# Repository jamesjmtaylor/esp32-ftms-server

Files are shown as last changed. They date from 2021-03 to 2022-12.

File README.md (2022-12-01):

# esp32-ftms-server

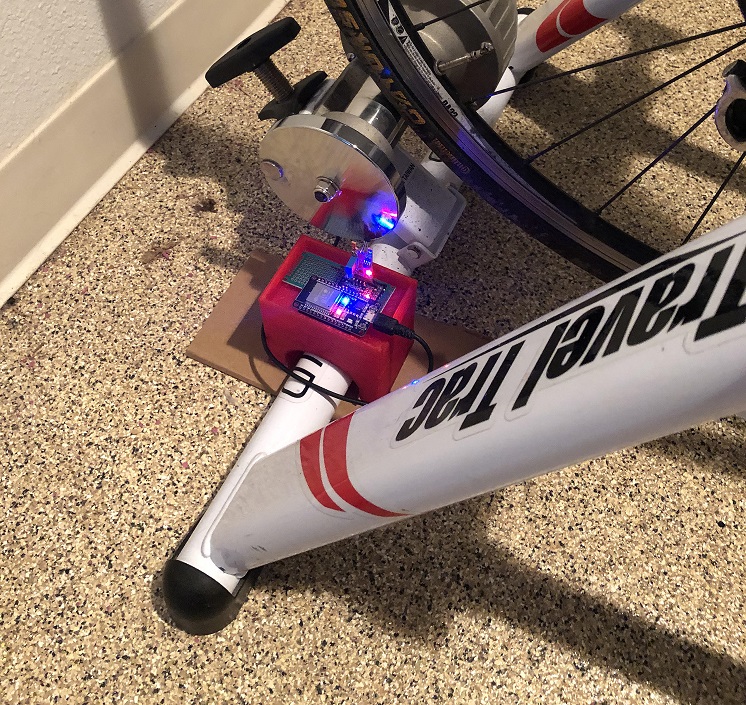
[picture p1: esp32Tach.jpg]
Tachometer
 

This is an ESP-32 based tachometer that I built for my stationary bike stand.  It uses the [Indoor Bike Data characteristic](https://www.bluetooth.com/wp-content/uploads/Sitecore-Media-Library/Gatt/Xml/Characteristics/org.bluetooth.characteristic.indoor_bike_data.xml) of the FTMS BLE service.

## Parts List

* [MELIFE 2 Pack for ESP32](https://www.amazon.com/MELIFE-Development-Dual-Mode-Microcontroller-Integrated/dp/B07Q576VWZ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)
* [ELEGOO 32 Pcs Double Sided PCB Board Prototype Kit](https://www.amazon.com/ELEGOO-Prototype-Soldering-Compatible-Arduino/dp/B072Z7Y19F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)
* [ELEGOO Upgraded 37 in 1 Sensor Modules Kit](https://www.amazon.com/ELEGOO-Upgraded-Tutorial-Compatible-MEGA2560/dp/B01MG49ZQ5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)
* [HATCHBOX ABS 3D Printer Filament](https://www.amazon.com/HATCHBOX-3D-Filament-Dimensional-Transparent/dp/B00M0CS6HA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)

## 3d Print Settings

The Cura 3d print settings for the tachMount.stl are below:

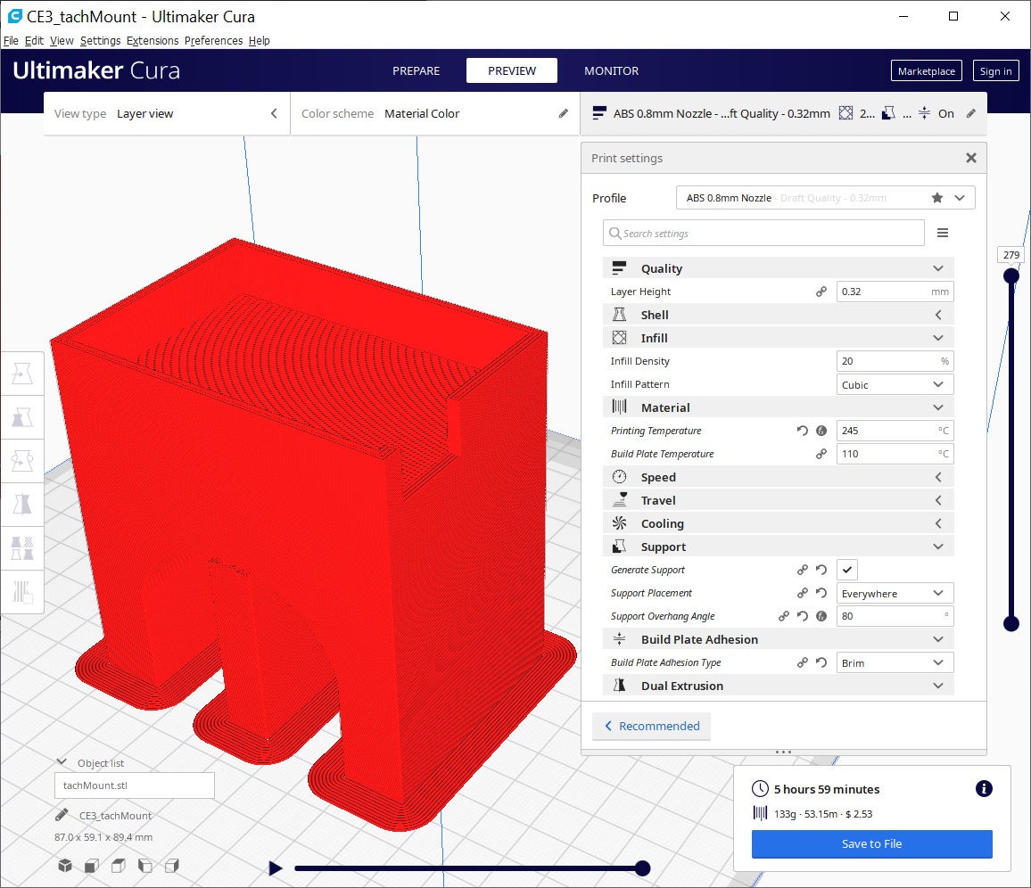
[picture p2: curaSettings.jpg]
Cura settings


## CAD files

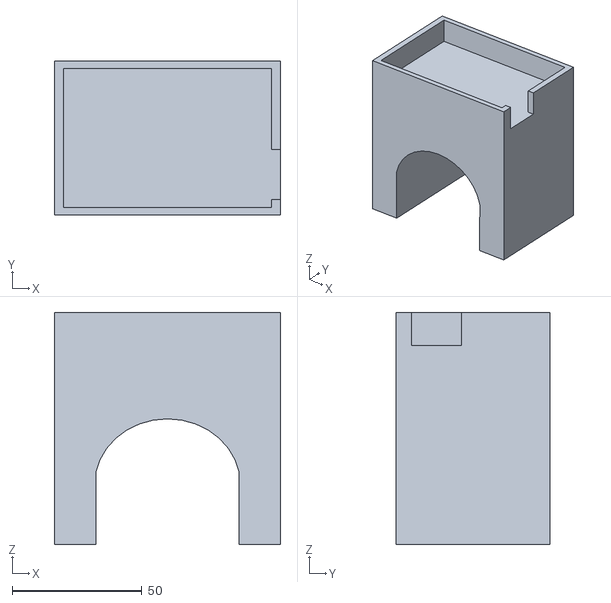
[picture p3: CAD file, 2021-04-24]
tachMount.stl
87.0 x 59.1 x 89.4

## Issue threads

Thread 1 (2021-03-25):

Cadence != RPM

jamesjmtaylor, 2021-03-25:
Cadence measures how fast the crankshaft rotates.  RPM measures how fast the road wheel rotates.

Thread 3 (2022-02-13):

Zwift (widows10) does not show up in the list of smart trainers on the device screen.

myashiro, 2022-02-13:
Zwift (widows10) does not show up in the list of smart trainers on the device screen.
It does show up in the list of power meters and cadence sensors.

jamesjmtaylor, 2022-02-14:
Could you elaborate on your issue?  Are you saying that the ESP32, when programmed with the logic established in this repository, does not show up in the Zwift app?

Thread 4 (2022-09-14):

Help to customize code

damndemento, 2022-09-14:
hi @jamesjmtaylor

I'm trying to use my schwinn ic7 bike magnet sensor - which fires once the wheel turns one round - to send ble-ftms data to a fitness app like zwift or rgt. I think your code can be helpful for my project, but I'm wondering why you declared an analog and a digital input pin. My plan was to connect sensor gnd to esp32 gnd and sensor signal to an input pin but unsure which to choose and why you've declared both.

I'm not familar with c++ / arduino programming but I think I can handle that if I understand your code a little better... I think I also have to recode the functions that calculate the kmh from rpm etc. but I think this shouldn't be too hard.

hope to get some explanation on that ;) thanks for sharing the code on github!

cheers
Dan

damndemento, 2022-09-14:
since this is not an issue with your code I close it...

jamesjmtaylor-dexcom, 2022-09-14:
Honestly I think the analog pin is a relic from when I was trying different input pins on my ESP32. I declared both so that I could alternate between them quickly as I swapped the wiring between them on my breadboard.  I'd suggest you do the same; try one and if the data doesn't make sense, try the other.

damndemento, 2022-09-14:
;) thank you! I'll see what fits for my sensor...

Closed 2022-09-14.

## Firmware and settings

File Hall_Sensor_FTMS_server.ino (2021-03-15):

/*
    Based on Neil Kolban example for IDF: https://github.com/nkolban/esp32-snippets/blob/master/cpp_utils/tests/BLE%20Tests/SampleServer.cpp
    Ported to Arduino ESP32 by Evandro Copercini
    updates by chegewara
*/

#include <BLEDevice.h>
#include <BLEUtils.h>
#include <BLEServer.h>
#include <BLE2902.h>
#include <math.h>

// See the following for generating UUIDs:
// https://www.uuidgenerator.net/

#define FTMS_UUID "00001826-0000-1000-8000-00805f9b34fb"
#define FITNESS_MACHINE_FEATURES_UUID "00002acc-0000-1000-8000-00805f9b34fb"
#define INDOOR_BIKE_DATA_CHARACTERISTIC_UUID "00002ad2-0000-1000-8000-00805f9b34fb"
#define LED_BUILTIN 2

bool deviceConnected = false;
bool oldDeviceConnected = false;
class MyServerCallbacks : public BLEServerCallbacks
{
    void onConnect(BLEServer *pServer)
    {
        deviceConnected = true;
    };

    void onDisconnect(BLEServer *pServer)
    {
        deviceConnected = false;
    }
};

void setup()
{
    pinMode(LED_BUILTIN, OUTPUT); // initialize digital pin LED_BUILTIN as an output.
    setupBluetoothServer();
    setupHalSensor();
}

BLECharacteristic *fitnessMachineFeaturesCharacteristic = NULL;
BLECharacteristic *indoorBikeDataCharacteristic = NULL;
BLEServer *pServer = NULL;
void setupBluetoothServer()
{
    Serial.begin(115200);
    Serial.println("Starting BLE work!");
    BLEDevice::init("IC Bike");
    pServer = BLEDevice::createServer();
    pServer->setCallbacks(new MyServerCallbacks());
    BLEService *pService = pServer->createService(FTMS_UUID);
    fitnessMachineFeaturesCharacteristic = pService->createCharacteristic(
        FITNESS_MACHINE_FEATURES_UUID,
        BLECharacteristic::PROPERTY_READ |
            BLECharacteristic::PROPERTY_WRITE |
            BLECharacteristic::PROPERTY_NOTIFY |
            BLECharacteristic::PROPERTY_INDICATE);
    indoorBikeDataCharacteristic = pService->createCharacteristic(
        INDOOR_BIKE_DATA_CHARACTERISTIC_UUID,
        BLECharacteristic::PROPERTY_READ |
            BLECharacteristic::PROPERTY_WRITE |
            BLECharacteristic::PROPERTY_NOTIFY |
            BLECharacteristic::PROPERTY_INDICATE);
    //  BLE2803 and BLE2902 are the UUIDs for Characteristic Declaration (0x2803) and Descriptor Declaration (0x2902).
    fitnessMachineFeaturesCharacteristic->addDescriptor(new BLE2902());
    indoorBikeDataCharacteristic->addDescriptor(new BLE2902());
    pService->start();
    // BLEAdvertising *pAdvertising = pServer->getAdvertising();  // add this for backwards compatibility
    BLEAdvertising *pAdvertising = BLEDevice::getAdvertising();
    pAdvertising->addServiceUUID(FTMS_UUID);
    pAdvertising->setScanResponse(true);
    pAdvertising->setMinPreferred(0x06); // functions that help with iPhone connections issue
    pAdvertising->setMinPreferred(0x12);
    BLEDevice::startAdvertising();
    Serial.println("Waiting for a client connection to notify...");
}

int digitalPin = 18;
int analogPin = 19;
bool magStateOld;
void setupHalSensor()
{
    pinMode(analogPin, INPUT);
    pinMode(digitalPin, INPUT);
    Serial.begin(9600);
    magStateOld = digitalRead(digitalPin);
}

//incrementRevolutions() used to synchronously update rev rather than using an ISR.
inline bool positiveEdge(bool state, bool &oldState)
{
    bool result = (state && !oldState);//latch logic
    oldState = state;
    return result;
}

double calculateRpmFromRevolutions(int revolutions, unsigned long revolutionsTime)
{
    double ROAD_WHEEL_TO_TACH_WHEEL_RATIO = 20.68;
    double instantaneousRpm = revolutions * 60 * 1000 / revolutionsTime / ROAD_WHEEL_TO_TACH_WHEEL_RATIO;
    //    Serial.printf("revolutionsTime: %d, rev: %d , instantaneousRpm: %2.9f \n",
    //                    revolutionsTime, revolutions, instantaneousRpm);
    return instantaneousRpm;
}

double calculateKphFromRpm(double rpm)
{
    double WHEEL_RADIUS = 0.00034; // in km
    double KM_TO_MI = 0.621371;

    double circumfrence = 2 * PI * WHEEL_RADIUS;
    double metricDistance = rpm * circumfrence;
    double kph = metricDistance * 60;
    double mph = kph * KM_TO_MI; 
                                        //    Serial.printf("rpm: %2.2f, circumfrence: %2.2f, metricDistance %2.5f , imperialDistance: %2.5f, mph: %2.2f \n",
                                        //                   rpm, circumfrence, metricDistance, imperialDistance, mph);
    return kph;
}

unsigned long distanceTime = 0;
double calculateDistanceFromKph(unsigned long distanceTimeSpan, double kph)
{
    double incrementalDistance = distanceTimeSpan * kph / 60 / 60 / 1000;
    //    Serial.printf("mph: %2.2f, distanceTimeSpan %d , incrementalDistance: %2.9f \n",
    //                   mph, distanceTimeSpan, incrementalDistance);
    return incrementalDistance;
}

double tireValues[] = {0.005, 0.004, 0.012};                      //Clincher, Tubelar, MTB
double aeroValues[] = {0.388, 0.445, 0.420, 0.300, 0.233, 0.200}; //Hoods, Bartops, Barends, Drops, Aerobar
unsigned long caloriesTime = 0;
double calculatePowerFromKph(double kph)
{
    //double velocity = mph * 0.44704; // translates to meters/second
    double velocity = kph * 0.277778; // translates to meters/second
    double riderWeight = 72.6;       //165 lbs
    double bikeWeight = 11.1;        //Cannondale road bike
    int theTire = 0;                 //Clinchers
    double rollingRes = tireValues[theTire];
    int theAero = 1; //Bartops
    double frontalArea = aeroValues[theAero];
    double grade = 0;
    double headwind = 0;        // converted to m/s
    double temperaturev = 15.6; // 60 degrees farenheit
    double elevation = 100;     // Meters
    double transv = 0.95;       // no one knows what this is, so why bother presenting a choice?

    /* Common calculations */
    double density = (1.293 - 0.00426 * temperaturev) * exp(-elevation / 7000.0);
    double twt = 9.8 * (riderWeight + bikeWeight); // total weight in newtons
    double A2 = 0.5 * frontalArea * density;       // full air resistance parameter
    double tres = twt * (grade + rollingRes);      // gravity and rolling resistance

    // we calculate power from velocity
    double tv = velocity + headwind;      //terminal velocity
    double A2Eff = (tv > 0.0) ? A2 : -A2; // wind in face so you must reverse effect
    return (velocity * tres + velocity * tv * tv * A2Eff) / transv;    
}

double calculateCaloriesFromPower(unsigned long caloriesTimeSpan, double powerv)
{
    double JOULE_TO_KCAL = 0.238902957619;
    // From the formula: Energy (Joules) = Power (Watts) * Time (Seconds)
    double incrementalCalories =  powerv * caloriesTimeSpan / 60 / 1000 * JOULE_TO_KCAL; 
    double wl = incrementalCalories / 32318.0;    // comes from 1 lb = 3500 Calories
    return incrementalCalories;
}

void indicateRpmWithLight(int rpm)
{
    if (rpm > 1)
    {
        digitalWrite(LED_BUILTIN, HIGH); // turn the LED on (HIGH is the voltage level)
    }
    else
    {
        digitalWrite(LED_BUILTIN, LOW); // turn the LED off by making the voltage LOW
    }
}

//Used for debugging, i.e. `printArray(bikeData, sizeof(bikeData));` 
//NOTE: sizeOfArray parameter is necessary 
//This is because `sizeOf()` will return the size of the pointer to the array, not the array
void printArray(byte input[], int sizeOfArray)
{
    for (size_t i = 0; i < sizeOfArray; i++) 
    {
        Serial.print(input[i]);
        Serial.print(' ');
    }
}

byte features[] = {0x07,0x52,0x00,0x00}; 
// 0x07,0x52 (0x48,0x4a in big-endian) are flags for
// avgSpeed (0), cadence (1), total distance (2), expended energy (9), elapsed time (12), power measurement (14)  
void transmitFTMS(double rpm, double avgRpm, double kph, double avgKph, double power, double avgPower, 
                  double runningDistance, double runningCalories, unsigned long elapsedTime)
{
    uint16_t transmittedKph     = (uint16_t) (kph * 100);         //(0.01 resolution)
    uint16_t transmittedTime    = (uint16_t) (elapsedTime / 1000);//(1.0 resolution) 
    uint16_t transmittedAvgKph  = (uint16_t) (avgKph * 100);      //(0.01 resolution)
    uint16_t transmittedRpm     = (uint16_t) (rpm * 2);           //(0.5 resolution)
    uint16_t transmittedAvgRpm  = (uint16_t) (avgRpm * 2);         //(0.1 resolution)
    uint16_t transmittedPower   = (uint16_t) (power * 2);      //(1.0 resolution)
    uint16_t transmittedAvgPower= (uint16_t) (avgPower * 2);        //(1.0 resolution)
    uint32_t transmittedDistance= (uint32_t) (runningDistance * 1000);// runningDistance in km, need m 
    uint16_t transmittedTotalCal= (uint16_t) (runningCalories * 10);                   //(1.0 resolution)
    uint16_t transmittedCalHr   = (uint16_t) (runningCalories * 60 * 60 / elapsedTime);//(1.0 resolution) 
    uint8_t transmittedCalMin   = (uint8_t)  (runningCalories * 60 / elapsedTime);     //(1.0 resolution)
    
    bool disconnecting = !deviceConnected && oldDeviceConnected;
    bool connecting = deviceConnected && !oldDeviceConnected;
    
    byte bikeData[20]={0x56,0x09, // these bytes are the flags for
                    // instSpeed (0 counts as true here), avgSpeed(1), instCadence (2),  
                    // total distance (4), instPower (6), expended energy (8), elapsed time (11)
                    (uint8_t)transmittedKph,       (uint8_t)(transmittedKph >> 8),
                    (uint8_t)transmittedAvgKph,    (uint8_t)(transmittedAvgKph >> 8),
                    (uint8_t)transmittedRpm,       (uint8_t)(transmittedRpm >> 8),
                    //(uint8_t)transmittedAvgRpm,    (uint8_t)(transmittedAvgRpm >> 8), //NOTE: commented out to avoid exceeding MTU                   
                    (uint8_t)transmittedDistance,  (uint8_t)(transmittedDistance >> 8),(uint8_t)(transmittedDistance >> 16),        
                    (uint8_t)transmittedPower,     (uint8_t)(transmittedPower >> 8), //NOTE: Actually SINT16, but my bike can't peddle backwards
                    //(uint8_t)transmittedAvgPower,(uint8_t)(transmittedAvgPower >> 8), //NOTE: commented out to avoid exceeding MTU                        
                    (uint8_t)transmittedTotalCal,  (uint8_t)(transmittedTotalCal >> 8),                    
                    (uint8_t)transmittedCalHr,     (uint8_t)(transmittedCalHr >> 8),                    
                    transmittedCalMin,
                    (uint8_t)transmittedTime,      (uint8_t)(transmittedTime >> 8)
      };
    if (deviceConnected)
    {
        //NOTE: Even though the ATT_MTU for BLE is 23 bytes, android by default only captures the first 20 bytes.
        indoorBikeDataCharacteristic->setValue((uint8_t *)&bikeData, 20);
        indoorBikeDataCharacteristic->notify();
    }
    
    if (disconnecting) // give the bluetooth stack the chance to get things ready & restart advertising
    {
        delay(500);                  
        pServer->startAdvertising(); 
        Serial.println("start advertising");
        oldDeviceConnected = deviceConnected;
    }
    
    if (connecting) // execute one time notification of supported features
    { 
        oldDeviceConnected = deviceConnected;
        fitnessMachineFeaturesCharacteristic->setValue((byte*)&features, 4);
        fitnessMachineFeaturesCharacteristic->notify();
    }
}

unsigned long elapsedTime = 0;
unsigned long elapsedSampleTime = 0;
int rev = 0;
double intervalEntries = 0;
double totalRpm = 0;
double totaKph = 0;
double totalPower = 0;
double runningCalories = 0.0;
double runningDistance = 0.0;
void loop()
{
    unsigned long intervalTime = millis() - elapsedTime;
    unsigned long sampleTime = millis() - elapsedSampleTime;
    bool state = digitalRead(digitalPin);
    if (sampleTime > 5 && state != magStateOld)
    {
        rev += (int)positiveEdge(state, magStateOld);
        elapsedSampleTime = millis();
    }
    if (intervalTime > 500)
    {
        double rpm = calculateRpmFromRevolutions(rev, intervalTime);
        double kph = calculateKphFromRpm(rpm);
        double power = calculatePowerFromKph(kph);
        
        intervalEntries++;
        totalRpm += rpm;
        totaKph += kph;
        totalPower += power;
        
        double avgRpm   = totalRpm   / intervalEntries;
        double avgKph   = totaKph    / intervalEntries;
        double avgPower = totalPower / intervalEntries;
        runningDistance += calculateDistanceFromKph(intervalTime, kph);
        
        runningCalories += calculateCaloriesFromPower(intervalTime, power);
        Serial.println("\n----------------------------------------------------");
        Serial.printf("elapsedTime: %d, rev: %d \n", elapsedTime, rev);
        Serial.printf("rpm: %2.2f, avgRpm: %2.2f \n", rpm, avgRpm);
        Serial.printf("kph: %2.2f, avgKph: %2.2f \n", kph, avgKph);
        Serial.printf("power: %2.2f watts, avgPower: %2.2 watts \n", power, avgPower);
        Serial.printf("distance: %2.2f, calories:  %2.5f \n", runningDistance, runningCalories);

        indicateRpmWithLight(rpm);
        // bluetooth becomes congested if too many packets are sent. In a 6 hour test I was able to go as frequent as 3ms.
        transmitFTMS(rpm,avgRpm,kph,avgKph,power,avgPower,runningDistance,runningCalories,elapsedTime);

        rev = 0;
        elapsedTime = millis();
    }
}

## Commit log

2021-02-02 Updated calorie calculation file so that it would compile. Updated BLE and loop logic so that the magnet status could be sent over bluetooth.
2021-02-14 Split each variable calculation into its own function. Used pure functions wherever possible. Added debugging statements. Working through issue where functions work with print statements, fail withou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
    [Hall_Sensor_FTMS_server.ino]
2021-02-14 Added sample time threshold to filter out sensor noise. Added average rpm and mph calculations.
    [Hall_Sensor_FTMS_server.ino]
2021-02-20 ESP now connects to Android device over BLE and notifies it of changes. Notifications are not formatted properly yet.
2021-02-23 Found issue with encoding, little endian vs big endian.
    [Hall_Sensor_FTMS_server.ino]
2021-02-28 Added logic to do an in-place reversal of the bits in a provided array, allowing FTMS to be converted from ESP32s little-endian system to ARMs big-endian system so that Android & iOS can read it.
    [Hall_Sensor_FTMS_server.ino]
2021-03-05 Added array debugging function. Fixed bytes reversing only on every other iteration. Cleaned up comments.
    [Hall_Sensor_FTMS_server.ino]
2021-03-07 Fixed endianness issue when encoding actual data values. It turned out that the bits were not reversed, just the bytes.
    [Hall_Sensor_FTMS_server.ino]
2021-03-12 Added all desired features. Running into issue with indoor bike data broadcast where none of the data is being displayed. Troubleshooting on Android device.
    [Hall_Sensor_FTMS_server.ino]
2021-03-15 Tweaked logic based on actual ratio between tach wheel and bike wheel.
2021-04-24 Added 3d printable stand file. Updated readme with brief project description, parts list, and print settings.
    [tachMount.stl]
